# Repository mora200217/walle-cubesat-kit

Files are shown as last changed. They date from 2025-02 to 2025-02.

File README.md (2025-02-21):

# 🌱 walle-cubesat-kit
 - [Diseño PCB](#pcb-design).
 - [Diseño Estructura](#estructura).
 - [Codigo](#codigo).

## PCB Design
El diseño de la PCB se realizó en Kicad 8.0.8.  
Esquematico: [TPI_v1.kicad_sch](PCB/TPI_v1.kicad_sch)  
Archivo PCB: [TPI_v1.kicad_pcb](PCB/TPI_v1.kicad_pcb)  
Archivos Gerber: [Fabric.rar](PCB/Fabric/Fabric.rar)

### Esquematico

## Codigo

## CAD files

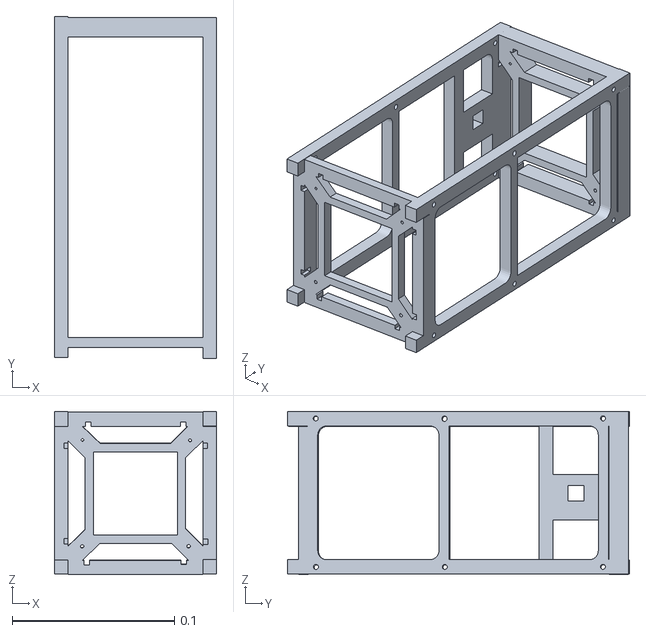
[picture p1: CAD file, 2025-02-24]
eva/public/cubesat.stl
0.1 x 0.21 x 0.101

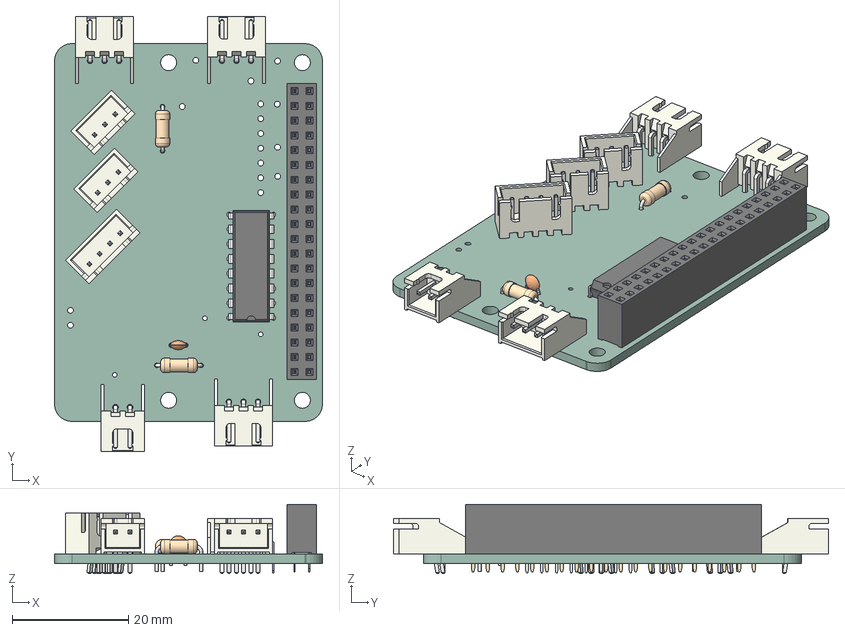
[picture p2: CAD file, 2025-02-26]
PCB/TPI_v1.step
46.1 x 74.7 x 11.9 mm
JST_B4B_XH_A
R_Axial_DIN0207_L63mm_D25mm_P762mm_Horizontal x 2
JST_S3B_XH_A_1 x 3
PinSocket_2x20_P2.54mm_Vertical
JST_B3B_XH_A x 2
JST_S2B_XH_A_1
DIP-16_W7.62mm
C_Disc_D30mm_W16mm_P250mm
TPI_v1_PCB

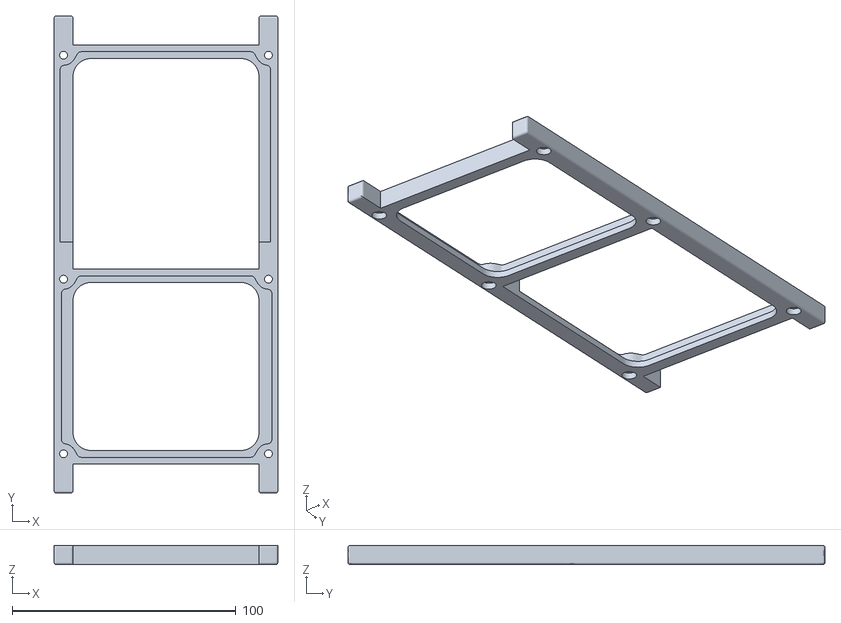
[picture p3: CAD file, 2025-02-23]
eva/public/example.stl
100.0 x 213.0 x 8.50

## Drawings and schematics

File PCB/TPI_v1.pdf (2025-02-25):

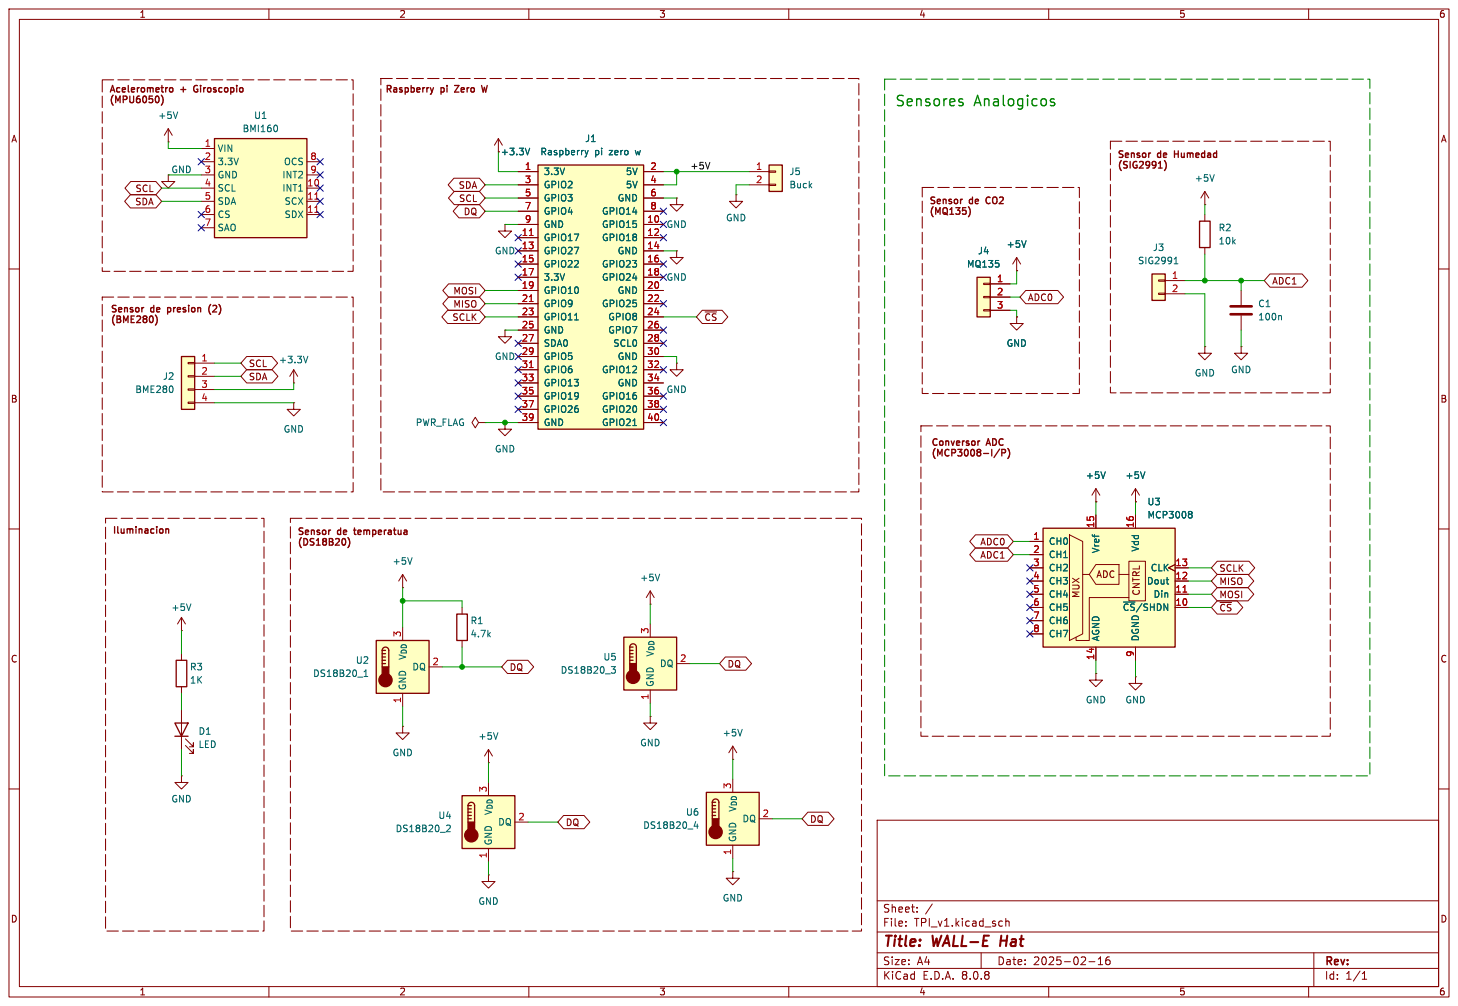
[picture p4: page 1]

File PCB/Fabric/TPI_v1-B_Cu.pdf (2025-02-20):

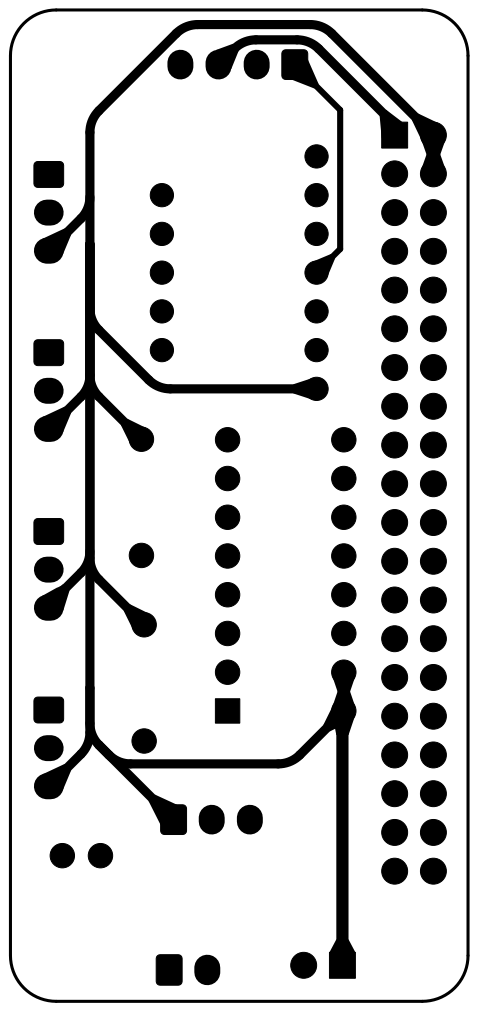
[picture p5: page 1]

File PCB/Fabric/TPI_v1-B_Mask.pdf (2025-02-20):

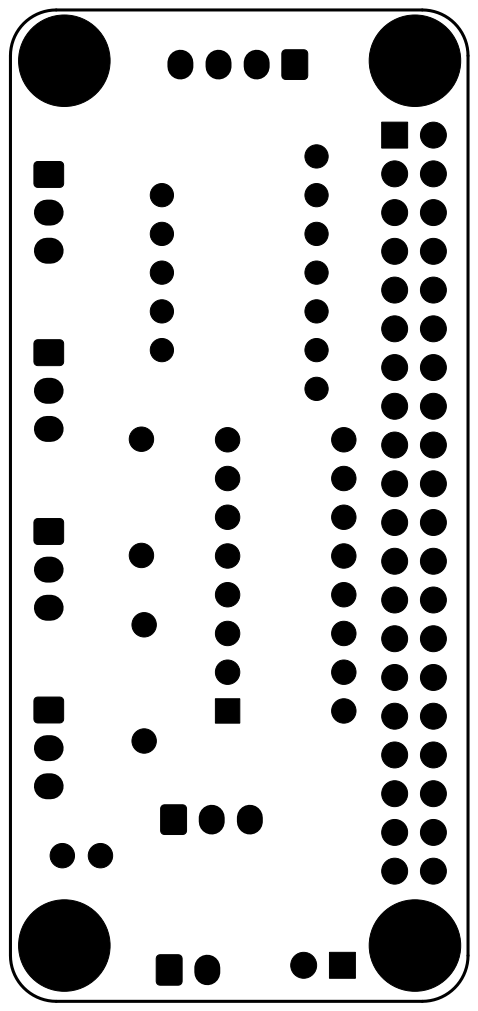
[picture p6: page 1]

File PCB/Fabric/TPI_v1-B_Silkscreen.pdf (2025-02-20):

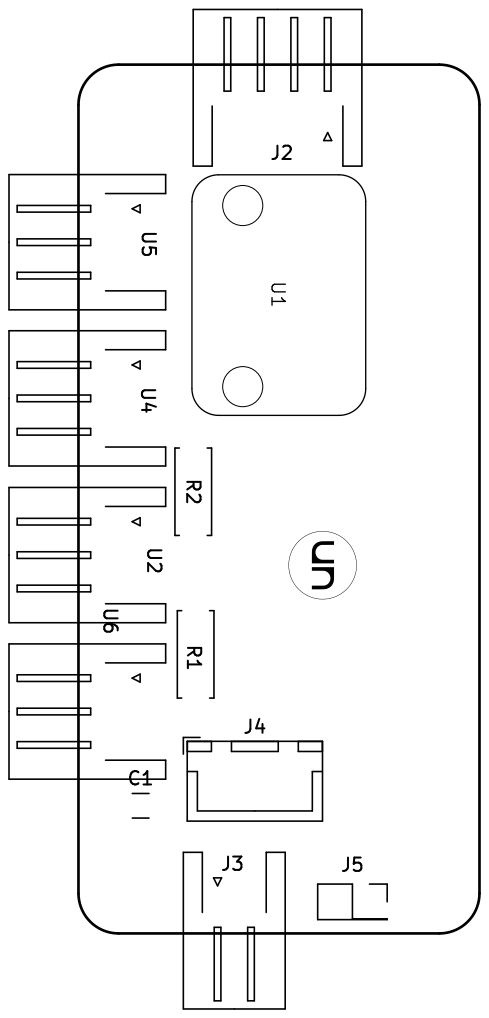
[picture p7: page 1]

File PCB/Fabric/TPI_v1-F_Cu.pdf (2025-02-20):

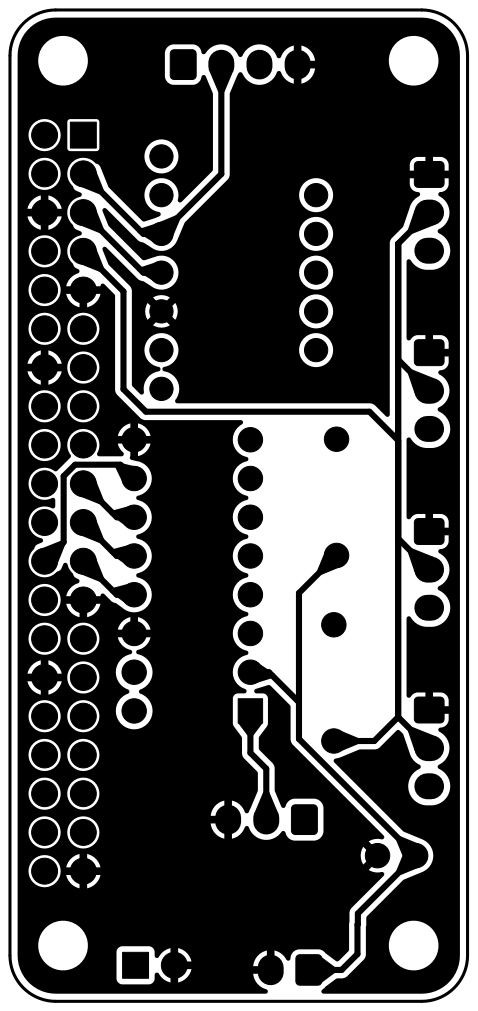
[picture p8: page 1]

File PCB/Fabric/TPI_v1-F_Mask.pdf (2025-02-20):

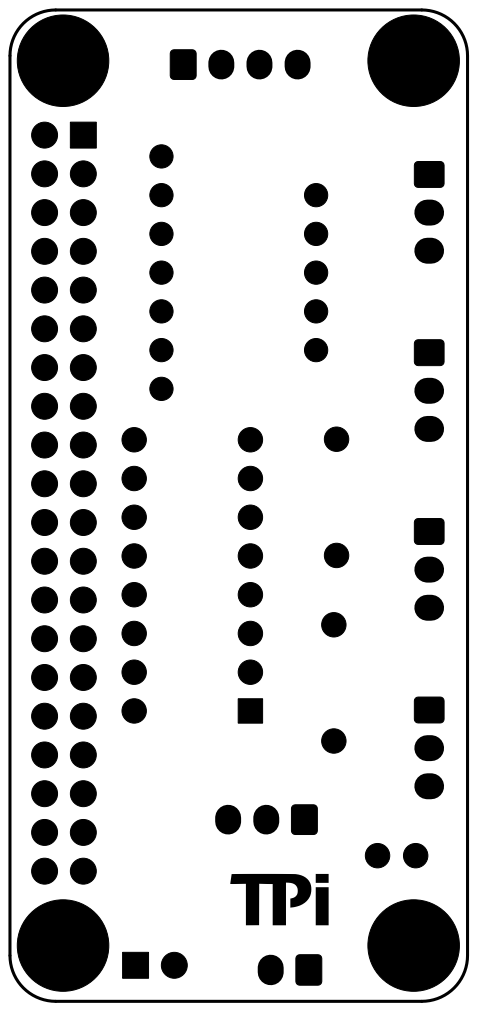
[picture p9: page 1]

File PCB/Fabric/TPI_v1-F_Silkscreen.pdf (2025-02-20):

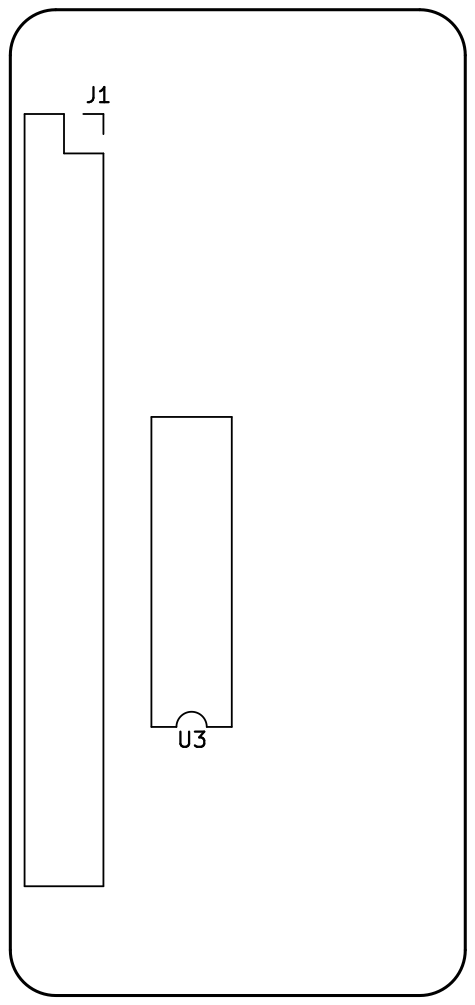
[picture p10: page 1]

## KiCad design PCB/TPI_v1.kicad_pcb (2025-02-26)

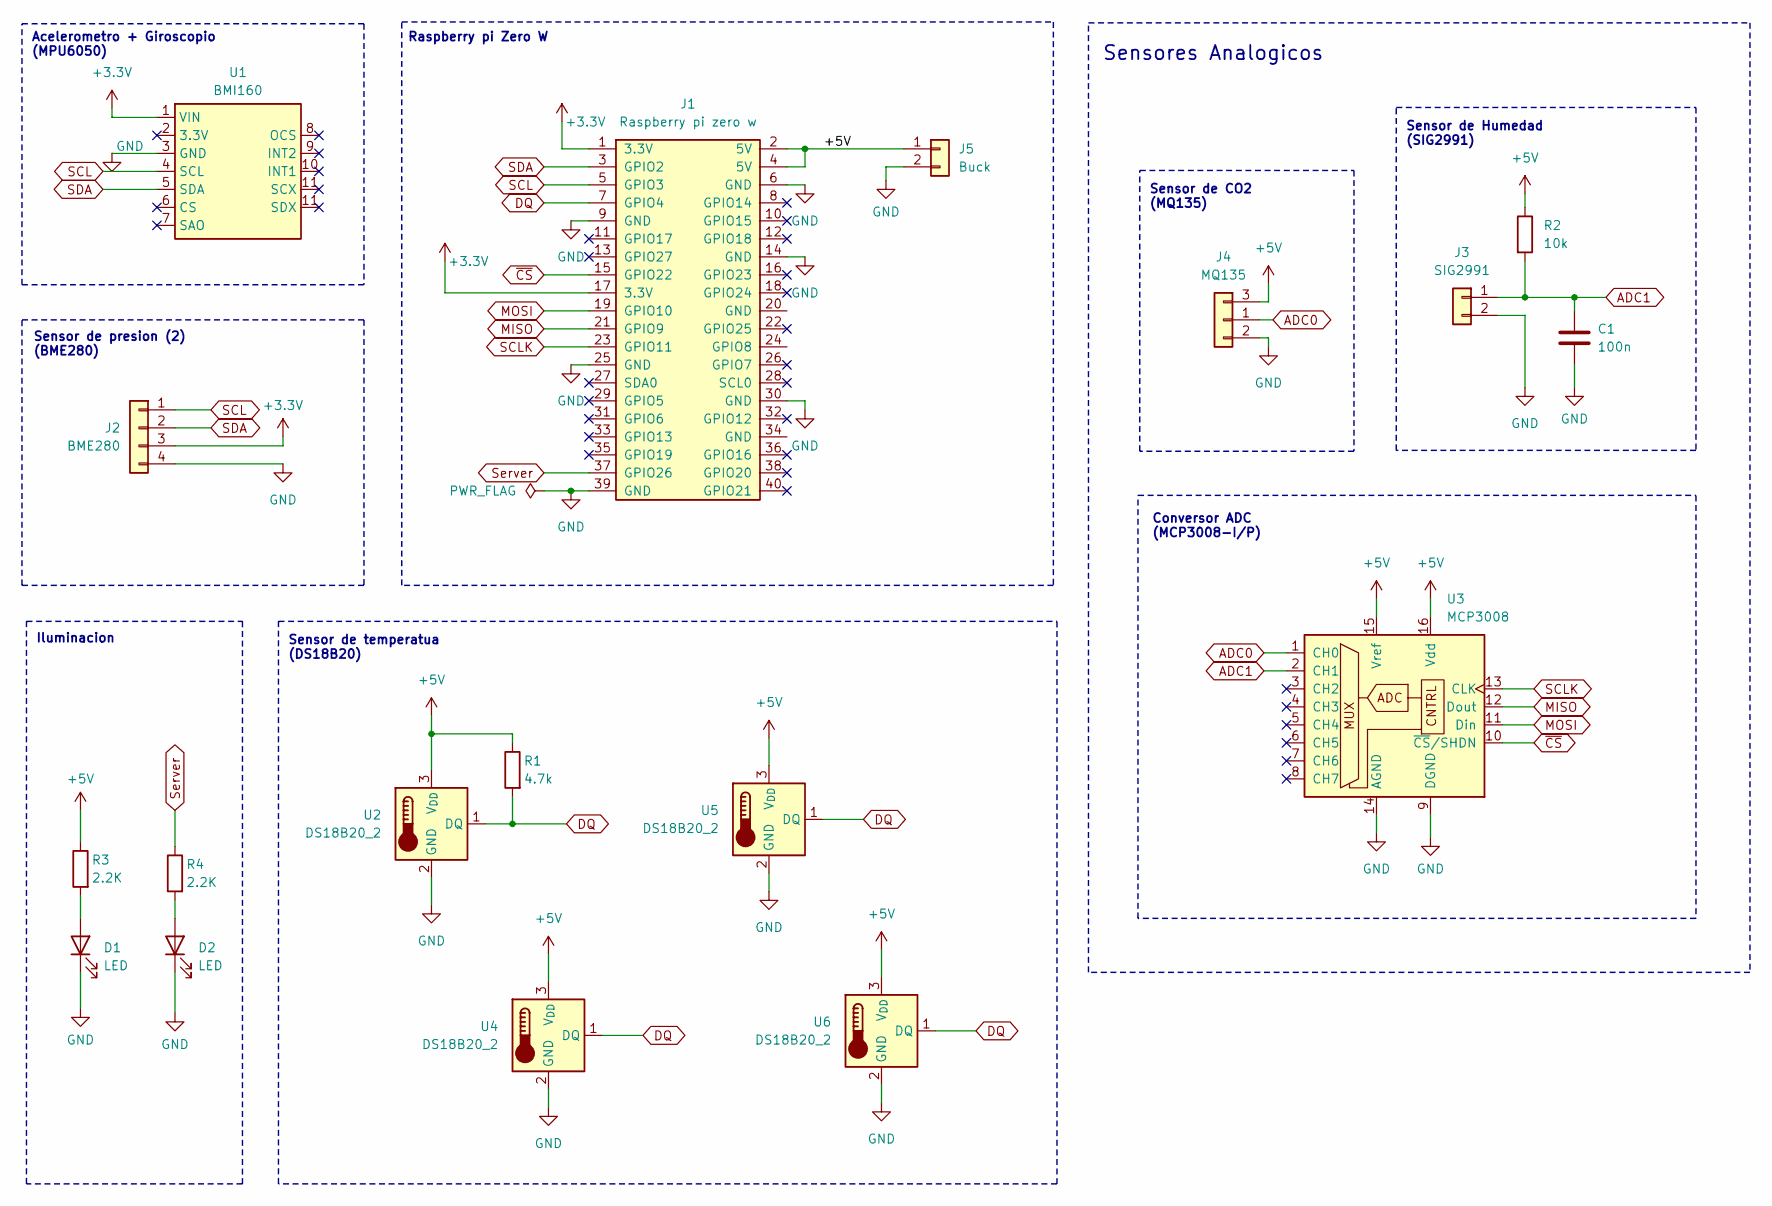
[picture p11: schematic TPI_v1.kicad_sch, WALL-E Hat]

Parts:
C1: 100n; C_Disc_D3.0mm_W1.6mm_P2.50mm
D1, D2: LED; LED_D3.0mm
J1: Raspberry pi zero w; PinHeader_2x20_P2.54mm_Vertical
J2: BME280; JST_XH_B4B-XH-A_1x04_P2.50mm_Vertical
J3: SIG2991; JST_XH_S2B-XH-A-1_1x02_P2.50mm_Horizontal
J4: MQ135; JST_XH_S3B-XH-A-1_1x03_P2.50mm_Horizontal
J5: Buck; PinSocket_2x01_P2.54mm_Vertical
R1: 4.7k; R_Axial_DIN0207_L6.3mm_D2.5mm_P7.62mm_Horizontal
R2: 10k; R_Axial_DIN0207_L6.3mm_D2.5mm_P7.62mm_Horizontal
R3, R4: 2.2K; R_Axial_DIN0207_L6.3mm_D2.5mm_P7.62mm_Horizontal
U1: BMI160
U2, U4: DS18B20_2; JST_XH_S3B-XH-A-1_1x03_P2.50mm_Horizontal
U3: MCP3008; DIP-16_W7.62mm
U5, U6: DS18B20_2; JST_XH_B3B-XH-A_1x03_P2.50mm_Vertical

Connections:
+3.3V: J1.1 (3.3V), J1.17 (3.3V), J2.3, U1.1 (VIN)
+5V: J1.2 (5V), J1.4 (5V), J4.3 (Pin_1), J5.1, R1.1, R2.1, R3.1, U2.3 (V_{DD}), U3.15 (Vref), U3.16 (Vdd), U4.3 (V_{DD}), U5.3 (V_{DD}), U6.3 (V_{DD})
ADC0: J4.1 (Pin_2), U3.1 (CH0)
ADC1: C1.1, J3.1, R2.2, U3.2 (CH1)
DQ: J1.7 (GPIO4), R1.2, U2.1 (DQ), U4.1 (DQ), U5.1 (DQ), U6.1 (DQ)
GND: C1.2, D1.1 (K), D2.1 (K), J1.6 (GND), J1.9 (GND), J1.14 (GND), J1.25 (GND), J1.30 (GND), J1.39 (GND), J2.4, J3.2, J4.2 (Pin_3), J5.2, U1.3 (GND), U2.2 (GND), U3.9 (DGND), U3.14 (AGND), U4.2 (GND), U5.2 (GND), U6.2 (GND)
MISO: J1.21 (GPIO9), U3.12 (Dout)
MOSI: J1.19 (GPIO10), U3.11 (Din)
unnamed: D1.2 (A), R3.2
unnamed: D2.2 (A), R4.2
SCL: J1.5 (GPIO3), J2.1, U1.4 (SCL)
SCLK: J1.23 (GPIO11), U3.13 (CLK)
SDA: J1.3 (GPIO2), J2.2, U1.5 (SDA)
Server: J1.37 (GPIO26), R4.1
~CS: J1.15 (GPIO22), U3.10 (~CS/SHDN)

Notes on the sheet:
Sensor de presion (2) (BME280)
Raspberry pi Zero W
Sensor de Humedad (SIG2991)
Conversor ADC (MCP3008-I/P)
Iluminacion
Sensor de temperatua (DS18B20)
Sensores Analogicos
Sensor de CO2 (MQ135)
Acelerometro + Giroscopio (MPU6050)

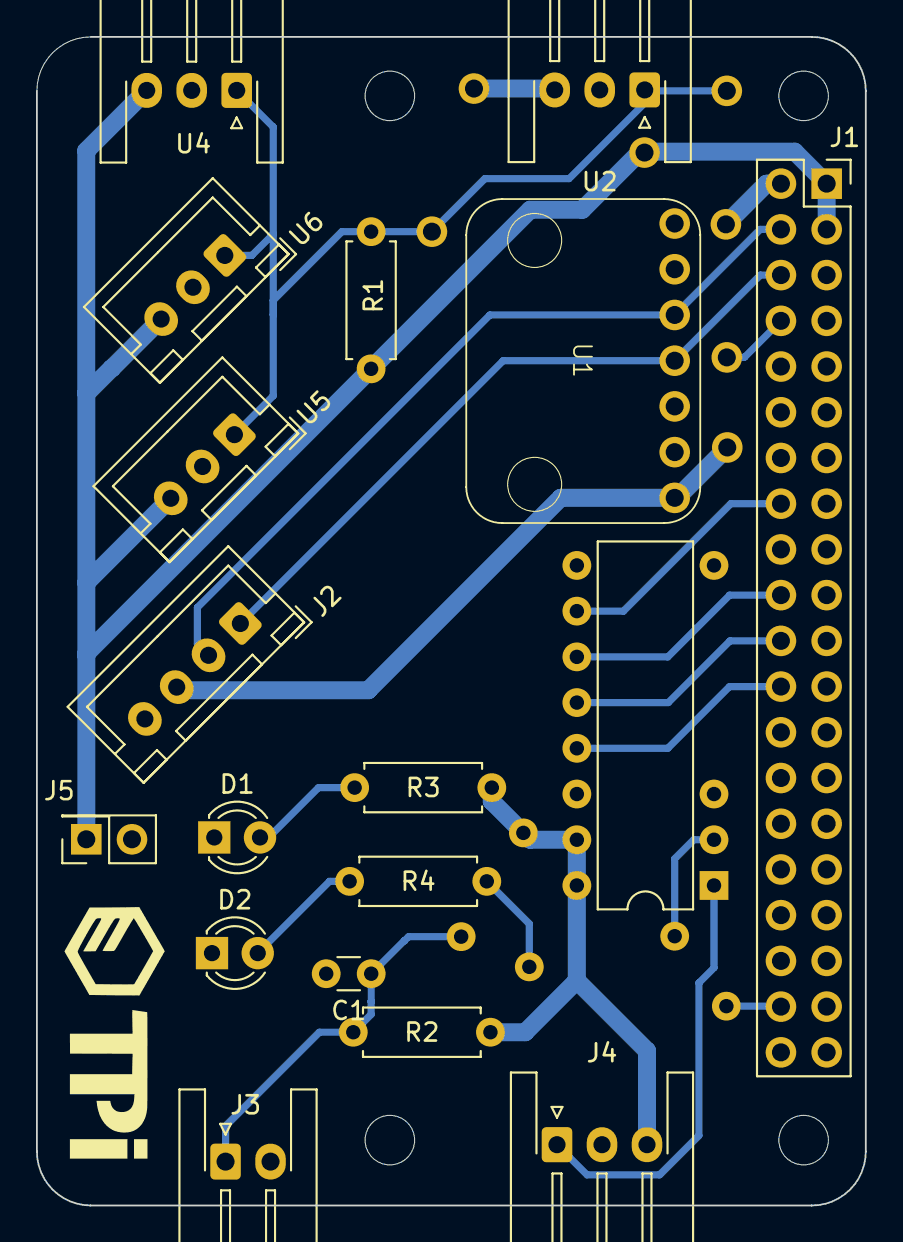
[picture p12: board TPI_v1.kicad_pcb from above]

Board: 2 copper layers, 46.1 x 64.9 mm, 18 parts (0 on the bottom side), 15 nets.

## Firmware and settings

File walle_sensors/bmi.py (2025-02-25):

"""
    IMU Sensor (BMI160) 
    -
"""
import time 
import math 
import numpy as np

from walle_sensors.sensor import Sensor
from walle_sensors.interfaces.i2c import I2C
# Initialize I2C with SMBus (Raspberry Pi uses SMBus for I2C)

class BMI(I2C, Sensor): 
    def __init__(self, addr): 
        super().__init__()
        self.set_i2c_address(addr)
        self.ACCEL_SENSITIVITY = 16384.0 

        self.ax_offset = 0
        self.ay_offset = 0
        self.az_offset = 0

        self.available = True

    def setup(self) -> bool:
        self.units = "m/s^2"
        self.available = True

        self.__auto_calibrate()
        try:
            self.write_register(0x7E, 0x11)  # ACC_NORMAL_MODE
            print("--Sensor BMI ok--")
        except Exception as e:
            print(f"Sensor BMI no conectado - Error: {e}")
            self.available = False

        time.sleep(0.1)

        return True 
    
    def read(self) -> np.array:
        self.available = True
        try:
            acc = np.array(self.__read_acceleration(self.ax_offset, self.ay_offset, self.az_offset))
            angles = np.array(self.__calculate_tilt_angles(acc[0] ,acc[1],acc[2] ))

            return angles
        except Exception as e:
            self.available = False
            print(" -!- Sensor BMI desconectado -!-")
            return np.array([None, None, None])


    def __read_raw_acceleration(self):
        """Read raw acceleration data."""
        data = self.read_register(0x12, 6)  # Read accel data
        ax_raw = int.from_bytes(data[0:2], 'little', signed=True)
        ay_raw = int.from_bytes(data[2:4], 'little', signed=True)
        az_raw = int.from_bytes(data[4:6], 'little', signed=True)
        return ax_raw, ay_raw, az_raw

    def __auto_calibrate(self):
        print("Starting auto-calibration...")
        num_samples = 100
        # self.ax_offset, self.ay_offset, self.az_offset = 0, 0, 0

        for _ in range(num_samples):
            ax_raw, ay_raw, az_raw = self.__read_raw_acceleration()
            self.ax_offset += ax_raw
            self.ay_offset += ay_raw
            self.az_offset += az_raw
            time.sleep(0.01)

        self.ax_offset //= num_samples
        self.ay_offset //= num_samples
        self.az_offset //= num_samples
        self.az_offset -= int(self.ACCEL_SENSITIVITY)  # Adjust for gravity

        print(f"Offsets - X: {self.ax_offset}, Y: {self.ay_offset}, Z: {self.az_offset}")
        return self.ax_offset, self.ay_offset, self.az_offset

    def __read_acceleration(self, ax_offset, ay_offset, az_offset):
        """Read acceleration data, apply offsets, and convert to m/s²."""
        ax_raw, ay_raw, az_raw = self.__read_raw_acceleration()
        ax = ((ax_raw - self.ax_offset) / self.ACCEL_SENSITIVITY) * 9.81
        ay = ((ay_raw - self.ay_offset) / self.ACCEL_SENSITIVITY) * 9.81
        az = ((az_raw - self.az_offset) / self.ACCEL_SENSITIVITY) * 9.81
        return ax, ay, az

    def __calculate_tilt_angles(self, ax, ay, az):
        """Calculate pitch and roll angles from acceleration."""
        pitch = math.atan2(ay, math.sqrt(ax**2 + az**2)) * 180.0 / math.pi
        roll = math.atan2(-ax, az) * 180.0 / math.pi
        return pitch, roll

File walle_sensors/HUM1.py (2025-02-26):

import RPi.GPIO as GPIO
from walle_sensors.interfaces.spi import SPI
from walle_sensors.sensor import Sensor


class HUM1(SPI, Sensor):
    def __init__(self, canal):
        super().__init__()
        self.canal = canal
        self.available = True

        CS_PIN = 15

        GPIO.setmode(GPIO.BCM)
        GPIO.setup(CS_PIN, GPIO.OUT)
        GPIO.output(CS_PIN, GPIO.HIGH)

    def setup(self) -> bool:
        print("--Sensor de humadad ok--")
        return True

    def read(self):
        self.available = True

        GPIO.output(CS_PIN, GPIO.LOW)
        command = [1, (8 + self.canal) << 4, 0]
        response = self.spi.xfer2(command)
        GPIO.output(CS_PIN, GPIO.HIGH)

        result = ((response[1] & 3) << 8) + response[2]
        humedad = (result * 100) / 1023

        if humedad <= 0:
            self.available = False
            return None


        return humedad

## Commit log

2025-02-19 PCB update
    [TPI_v1.kicad_pcb, TPI_v1.kicad_sch]
2025-02-19 [Update] sensor
    [example.stl]
2025-02-19 [Update] sensor bMI
2025-02-19 [Update] Correction with I2C communication"
2025-02-20 PCB
    Se cambio el voltaje del sensor BME280
    [TPI_v1.kicad_pcb, TPI_v1.kicad_sch, TPI_v1.step]
2025-02-21 BME
    Se mejoro el codigo del bme280
2025-02-21 Submit gerbers
    [TPI_v1-B_Cu.gbr, TPI_v1-B_Mask.gbr, TPI_v1-B_Silkscreen.gbr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]
2025-02-23 [Update] camera functional
    [example.stl]
2025-02-23 Update Sensors
2025-02-24 [New] Chart base. Better oganization folder in project root
    [cubesat.stl]
2025-02-24 Update sensors
    Cambio del available como atributo en vez de funcion
2025-02-26 PCB update
    V2 PCB
    [TPI_v1.kicad_pcb, TPI_v1.kicad_sch, TPI_v1.step]
2025-02-26 General update
    [TPI_v1-B_Cu.gbr, TPI_v1-B_Mask.gbr, TPI_v1-B_Silkscreen.gbr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]
